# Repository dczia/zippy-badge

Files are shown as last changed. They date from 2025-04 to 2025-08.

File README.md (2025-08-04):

```
 ______                   ____            _            
|__  (_)_ __  _ __  _   _| __ )  __ _  __| | __ _  ___ 
  / /| | '_ \| '_ \| | | |  _ \ / _` |/ _` |/ _` |/ _ \
 / /_| | |_) | |_) | |_| | |_) | (_| | (_| | (_| |  __/
/____|_| .__/| .__/ \__, |____/ \__,_|\__,_|\__, |\___|
       |_|   |_|    |___/                   |___/      
```

DCZia Presents: The 2025 Zippy Badge

It blinks, it bloops*, it does stuff.

**Hardware**
* PiPico 2040 MCU
* Between 1 and 42 NeoPixel LEDs
* Microphone, accelerometer, and a SD card slot (not implemented, but go wild if you want)
* Powered by USB C or AA batteries.

\* Blooping not avaliable in all areas, not valid in NJ, void where prohibited, if you experience a rash or itching ask your doctor if blooping is right for you.

**User Manual**

As of Defcon, the UI is as follows - there is a four direction joystick on the right side of the badge. Clicking it in, will chnage modes, up and down will change brightness, and left and right do nothing for now. The first mode is the rainbow mode, mode 2 is accelerometer reactive and tilting the badge left, right, forward or back, will change the color. Mode 3 is a sound reactive party mode, and we tried to make an auto senseing volume / gain adjustment, but we will see if it works for parties, or if its just pegged. Power switch is on the bottom if you are using batteries, and the DFU programming buttion is well recessed (sorry) next to it. 

**Assembly / Disassembly**

The badge comes fully assembled. You can power it with a usb-c cable and a power supply of your choosing. You can also solder on the included AA battery pack. On the back of the board there are two pads, marked + and - Solder the red wire from the battery holder to the + and the black wire to the - 

Head to the HHV if you need help soldering. The case screws on with four screws. They are M2x4, self tapping or machine. You can download our shell design and print your own if you wish. Let us know if you make something cool!

**Programming / Updating**

The badge is powered by a Raspberry Pi 2040 MCU. You can find official docs for progamming here https://www.raspberrypi.com/products/rp2040/

The TL;DR is - copy our repo, plug the badge into your computer and you should see a drive appear (or not if you rolled your own linux distro that has no automounter, but you probably know what to do here already, if thats you) called "Circuitpython" Drag the files inside our repo's software directory to that drive (the .py files, and library folders). After the files are copied the badge should reboot with the new code. Sometimes the badge can reboot early and get in a weird state. You can delete everything on the drive and try again. If the badge is in a really weird state, you can hold down the bootloader button while the badge is unplugged, plug it in, and you should see a different named drive appear. Here you can drop our U2F firmwre blob which has circuitpython and our code in one file to update the badge. Hit us up on Discord / BSky if you have questions, or drop an issue here.

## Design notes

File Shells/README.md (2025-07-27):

# Zippy Shell

The DCZia Zippy Badge was designed with a translucent shell to both protect the electronics as well as to give that retro vibe.  Included here are the source files for the shell so you can make your own.

The SolidWorks files were made with the Maker's edition, which may give you problems if you actually have access to the real version.

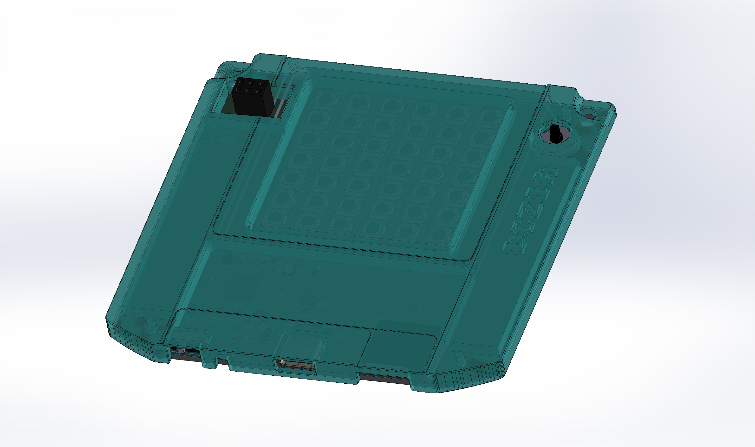
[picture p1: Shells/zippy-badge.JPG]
Badge


Additionally, a STEP file of the PCB board is provided, along with the SolidWorks assembly of the whole badge so you can see how your modeling changes affect the shell.

STEP is a bit better for doing changes with in CAD.  STL is what most slicers use, so you can use your slicer to make mods as well - but you can usually import STEP files as well.

Two different shells are provided:  

## Flat
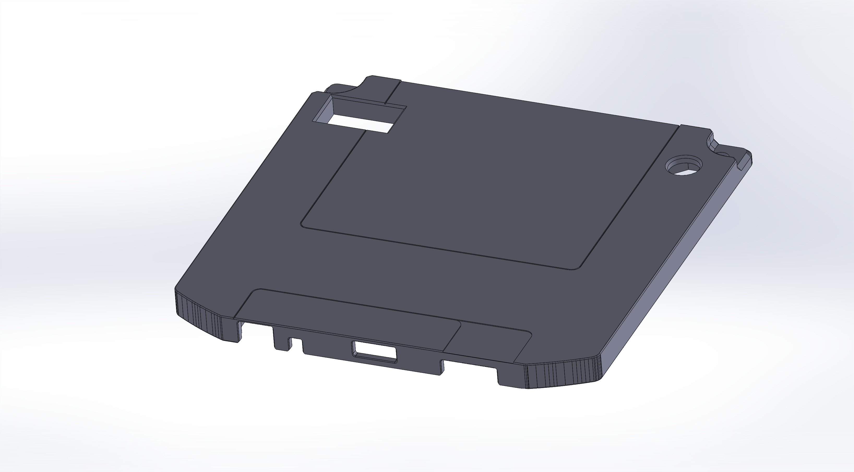
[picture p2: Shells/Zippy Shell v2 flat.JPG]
Flat
 

The 'flat' one is designed to work on a FDM printer.  Print it with the flat side down.  10% infill is good enough.

## Curved
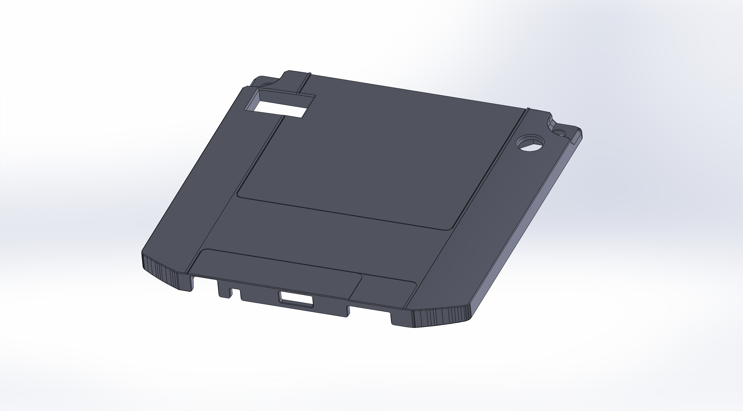
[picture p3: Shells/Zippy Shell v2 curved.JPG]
Curved


The 'curbed' one is like the original Zip disk with the curved outer edges.  This one works well for resin printing.

## Mounting

To mount the shell, there are 4 bolt holes provided, that work with M2 bolts, 4mm long.  Press firmly as you screw in - the plastic easily strips, but this method also works pretty well at this size, so... good luck.  The bolt hole locations are circled in red.

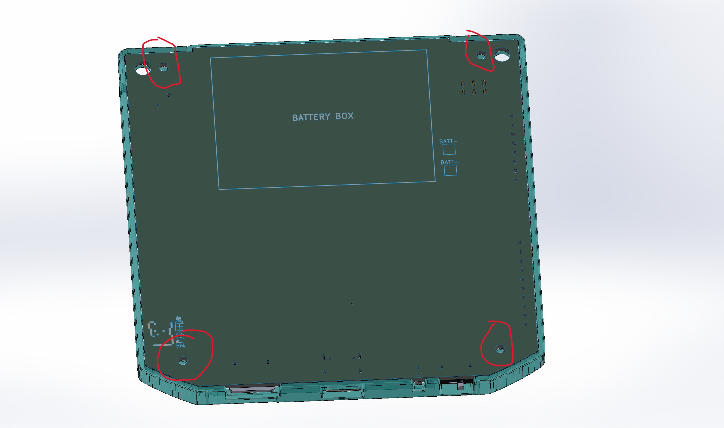
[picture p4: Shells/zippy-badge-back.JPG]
Bolts


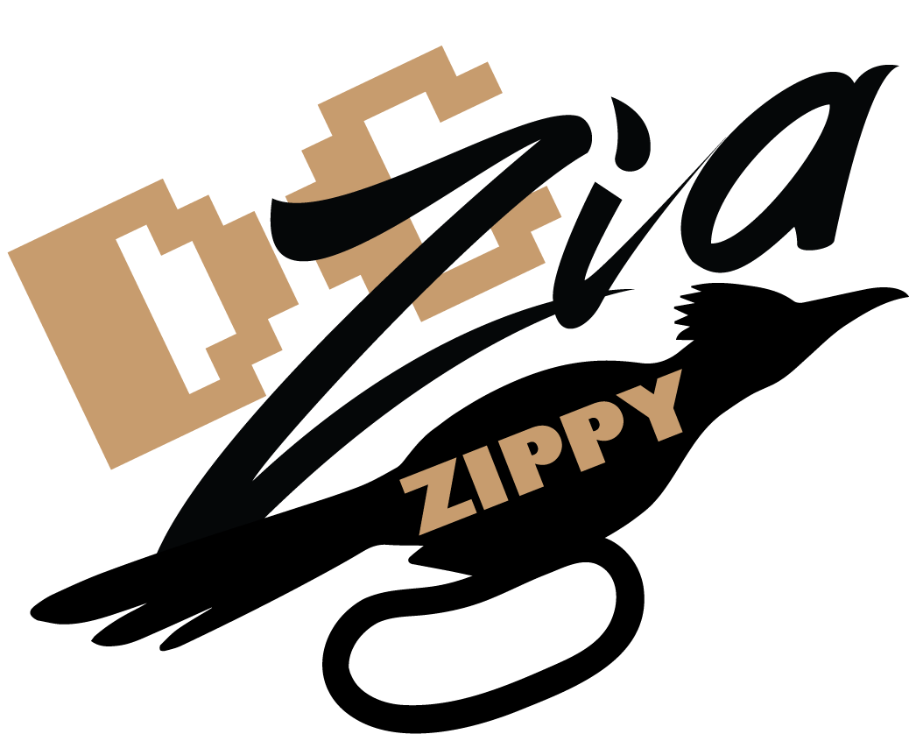
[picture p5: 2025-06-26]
Hardware/images/dczia zippy.png

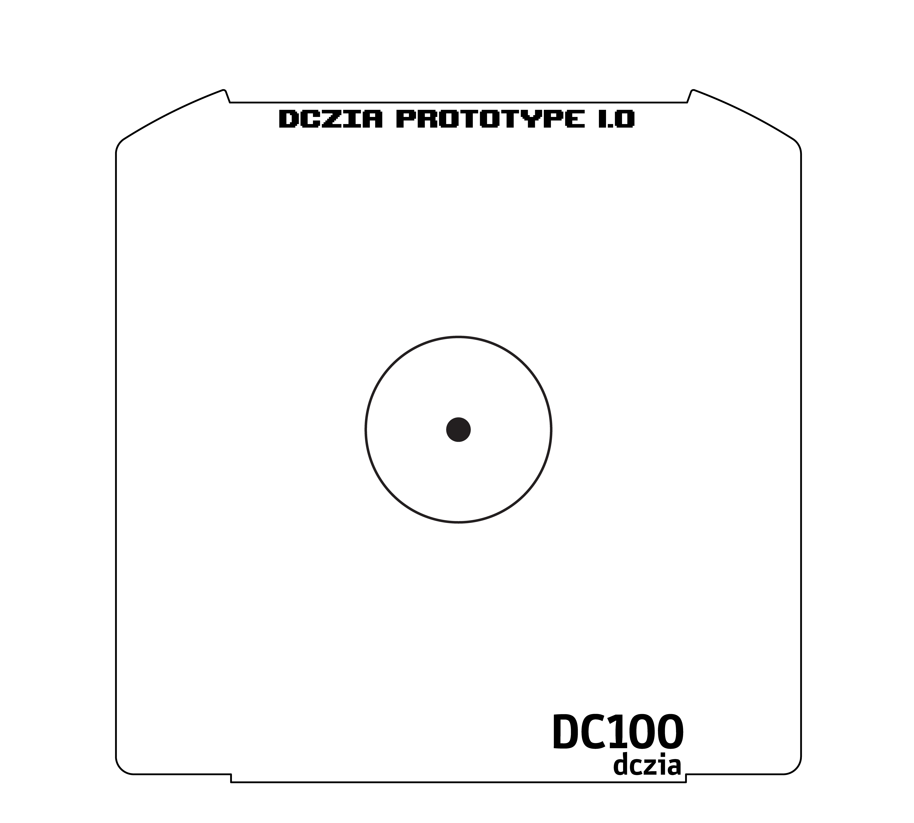
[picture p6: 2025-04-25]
Hardware/images/Proto Uno/ZipDisk100MBASM-02.png

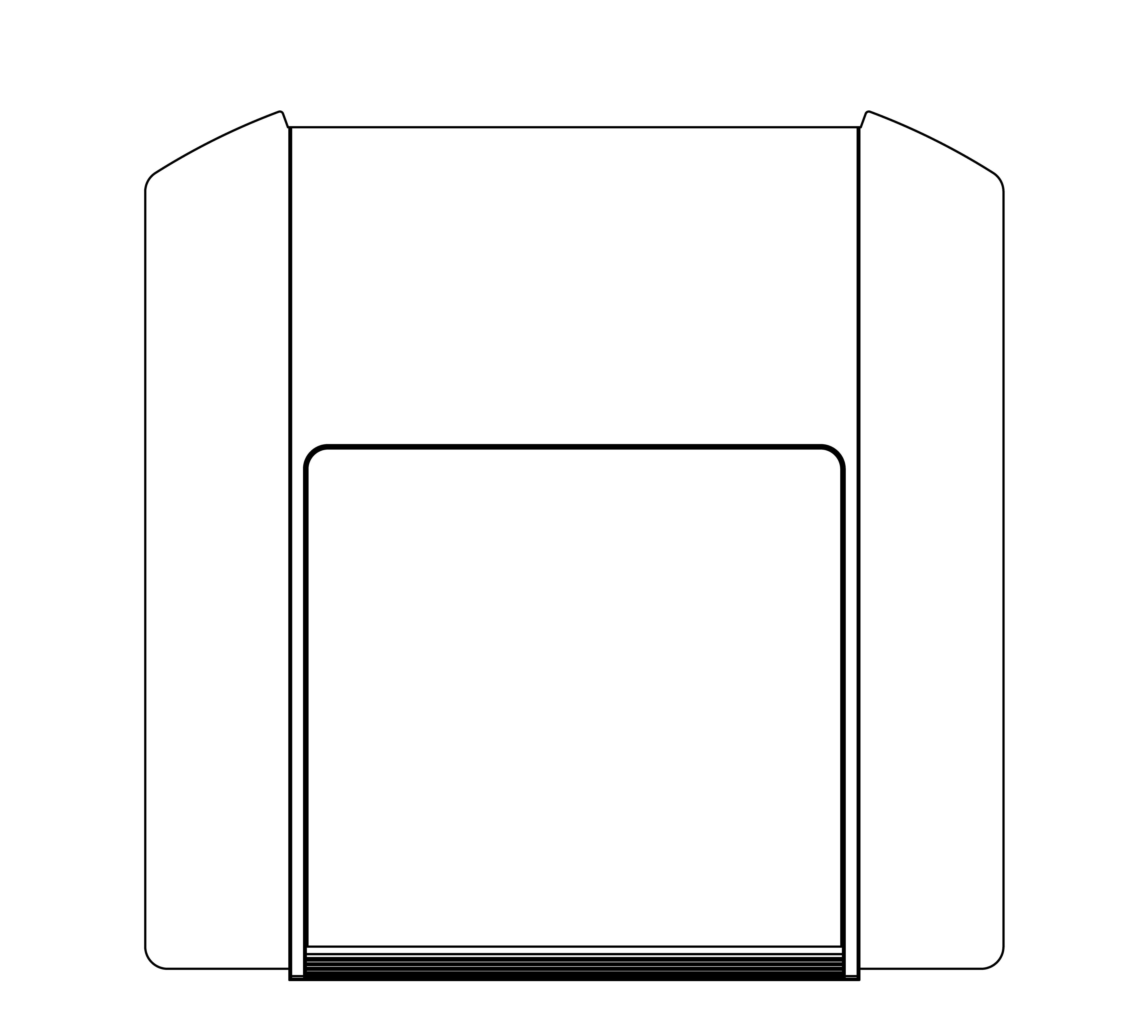
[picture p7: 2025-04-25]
Hardware/images/Proto Uno/ZipDisk100MBASM-01.png

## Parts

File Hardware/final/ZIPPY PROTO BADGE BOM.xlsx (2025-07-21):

Reference | Feeder | Value | Footprint | Part Number | Distributor | Distributor Part | Datasheet | Qty | Cost Each | Cost per Badge | Qty Needed | Qty Ordered | QOH | Notes
C1, C2, C3, C4, C5, C6, C7, C12, C15, C16, C17, C18, C19, C20, C21, C22 |  | 0.1uF | 0603 |  |  |  | ~ | 14 | 0.004 | 0.056 | 0 | 0 | 5000
C8,C9,C10,C14 |  | 1uF | 0603 |  |  |  | ~ | 4 | 0.004 | 0.016 | 0 | 4000
C11,C13 |  | 15pF | 0603 |  |  |  | ~ | 2 | 0.004 | 0.008 | 0 | 4000
D1, D45 |  | D_Schottky | Diode_SMD:D_SOD-523 |  |  |  | ~ | 2 | 0.11 | 0.22 | 100 |  | 0
D2,D3,D4,D5,D6,D7,D8,D9,D10,D11,D12,D13,D14,D15,D16,D17,D18,D19,D20,D21,D22,D23,D24,D25,D26,D27,D28,D29,D30,D31,D32,D33,D34,D35,D36,D37,D38,D39,D40,D41,D42,D43 |  | WS2812B | LED_SMD:LED_WS2812B_PLCC4_5.0x5.0mm_P3.2mm |  | Aliexpress | https://www.aliexpress.us/item/2251832628463811.html | https://cdn-shop.adafruit.com/datasheets/WS2812B.pdf | 42 | 0.07 | 2.94
D44 |  | TVS |  | SP0502BAHTG | Mouser | 576-SP0502BAHTG | https://www.littelfuse.com/assetdocs/tvs-diode-array-spasp050xba-lead-free-green-datasheet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 | 0 | 0.383 | 0 |  |  |  | Optional stuffing
J1 |  | Micro_SD_Card_SPI | lib_fp:MicroSD-Socket-Seeed-320090008 |  | Aliexpress |  | https://statics3.seeedstudio.com/images/opl/datasheet/320090008.pdf | 1 | 0.08 | 0.1 | 0 | 0
J2 |  | USB-C | Connector_USB:USB_C_Receptacle_HCTL_HC-TYPE-C-16P-01A |  | Aliexpress | https://www.aliexpress.us/item/3256805324706422.html | https://www.lcsc.com/datasheet/lcsc_datasheet_2211161000_HCTL-HC-TYPE-C-16P-01A_C2894897.pdf | 1 | 0.19 | 0.2 | 0 | 0
J3 |  | 1x8 Pin Header |  |  |  |  |  |  |  |  |  |  |  | DNS
J4 |  | 1x10 Pin Header |  |  |  |  |  |  |  |  |  |  |  | DNS
R1,R8 |  | 1k | 0603 |  |  |  | ~ | 2 | 0.001 | 0.002 | 0 | 0 | 5000
R2,R7 |  | 10k | 0603 |  |  |  | ~ | 2 | 0.001 | 0.002 | 0 | 0 | 5000
R3,R4 |  | 5.1k | 0603 |  |  |  | ~ | 2 | 0.001 | 0.002 |  | 5000
R5,R6 |  | 27R | 0603 |  |  |  | ~ | 2 | 0.001 | 0.002 |  | 5000
R9 |  | 10R | 0603 |  |  |  | ~ | 1 | 0.001 | 0.001 | 0 | 0 | 5000
SW1 |  | Boot Select | Button_Switch_SMD:SW_SPST_EVQP7C | EVQ-P7C01P | Mouser | 667-EVQP7C01P | ~ | 1 | 0.214 | 0.214 |  | 150
SW2 |  | SW_SPDT | lib_fp:SW_SPDT_CK-JS102011SAQN | JS102011SAQN | Mouser | 611-JS102011SAQN | https://ckswitches.com/media/1422/js.pdf | 1 | 0.463 | 0.463 |  | 150
SW3 |  | D-Pad | SKRHABE010 | SKRHABE010 | Mouser | 688-SKRHAAE010 | https://www.mouser.com/datasheet/2/15/SKRH-1370966.pdf | 1 | 2.02 | 2.02 | 0 | 0
TP1 |  | BATT+ | TestPoint:TestPoint_Pad_2.5x2.5mm | VIRTUAL |  |  | ~ | 1 |  | 0
TP2 |  | BATT- | TestPoint:TestPoint_Pad_2.5x2.5mm | VIRTUAL |  |  | ~ | 1 |  | 0
TP3 |  | SWCLK | TestPoint:TestPoint_Pad_2.5x2.5mm | VIRTUAL |  |  | ~ | 1 |  | 0
TP4 |  | SWD | TestPoint:TestPoint_Pad_2.5x2.5mm | VIRTUAL |  |  | ~ | 1 |  | 0
TP5, TP6 |  | Spare |  | VIRTUAL
U1 |  | NCP115ASN330T2G | Package_TO_SOT_SMD:SOT-23-5 | NCP115ASN330T2G | Mouser | 863-NCP115ASN330T2G | http://www.st.com/resource/en/datasheet/ld39015.pdf | 1 | 0.099 | 0.099 | 0 | 0 | 3000
U2 |  | RP2040 | Package_DFN_QFN:QFN-56-1EP_7x7mm_P0.4mm_EP3.2x3.2mm | SC0914(7) | Mouser | 358-SC09147 | https://datasheets.raspberrypi.com/rp2040/rp2040-datasheet.pdf | 1 | 0.8 | 0.8 | 0 | 0
U3 |  | W25Q16JV | lib_fp:W25Q16JVUXIQ_WIN | W25Q32RVXHJQ TR | Mouser | 454-W25Q32RVXHJQTR | https://www.winbond.com/hq/support/documentation/downloadV2022.jsp?__locale=en&level=1 | 1 | 0.481 | 0.481 |  | 150
U4 |  | GSDA213 | Kionix_LGA-12_2x2mm_P0.5mm_LayoutBorder2x4y | GSDA213 | Digikey | 4786-GSDA213TR-ND | https://goodarksemi.com/docs/datasheets/mems/GSDA213_SDS.pdf | 1 | 0.5868 | 0.5868 | 0 | 150
MK1 |  | ICS-43434 | InvenSense_ICS-43434-6_3.5x2.65mm | ICS-43434 | Aliexpress |  |  | 1 | 1.084 | 1.084 | 0 | 175
X1 |  | Badgelife_sao_connector_v169bis | lib_fp:Badgelife-Shitty-v1.69bis | VIRTUAL |  |  |  | 1 |  | 0
Y1 |  | Crystal | Crystal:Crystal_SMD_3225-4Pin_3.2x2.5mm | ABM8-272-T3 | Mouser | 815-ABM8-272-T3 | https://www.mouser.com/datasheet/2/3/ABM8_272_T3-3392615.pdf | 1 | 0.409 | 0.409 |  | 150
` |  | Battery boxes |  |  | Aliexpress | https://www.aliexpress.us/item/3256806115765872.html |  | 1 | 0.506 | 0.506 |  | 125
 |  | PCB |  |  |  |  |  | 1 | 2.175 | 2.175 |  | 200
 |  | Batteries |  |  | Amazon |  |  | 3 | 0.15 | 0.45 |  | 300
 |  |  |  |  |  |  |  | Total Parts |  | 12.8368

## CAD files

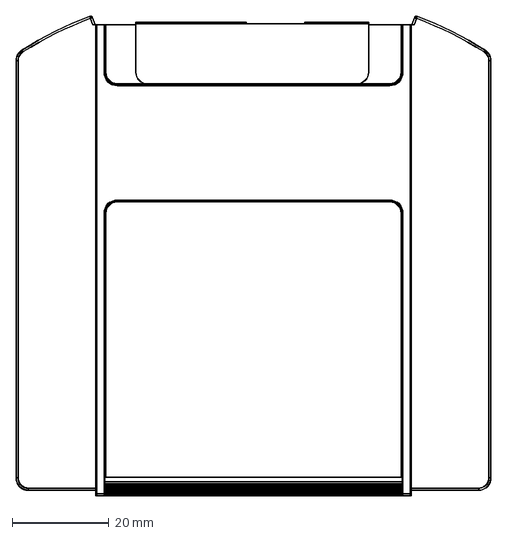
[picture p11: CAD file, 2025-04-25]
Hardware/images/Proto Uno/ZipDisk100MBASM.DXF
97.9 x 99.0 mm

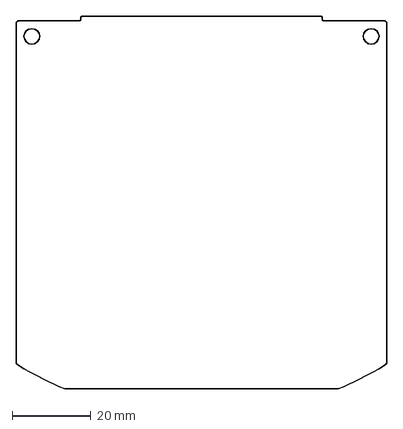
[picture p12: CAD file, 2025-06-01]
Hardware/images/Zippy Badge.dxf
94.4 x 94.9 mm

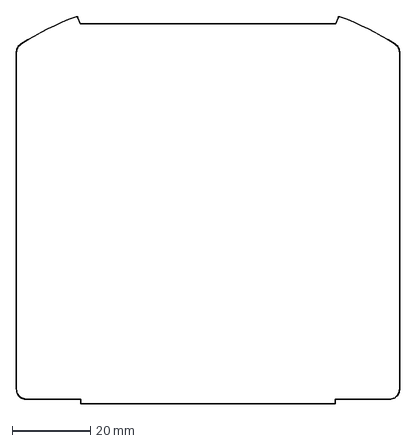
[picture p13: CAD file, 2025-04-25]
Hardware/images/Proto Uno/Zip Outline.dxf
97.9 x 99.0 mm

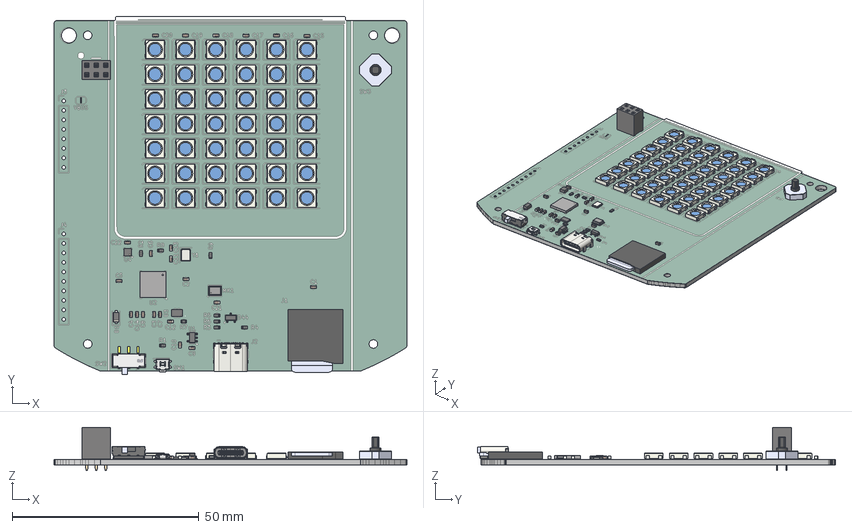
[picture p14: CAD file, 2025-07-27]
Shells/zippy-badge-PCB.step
94.4 x 95.9 x 11.6 mm
LED_WS2812B_PLCC4_5.0x5.0mm_P3.2mm x 42
C_0603_1608Metric x 22
USB_C_Receptacle_GCT_USB4105-xx-A_16P_TopMnt_Horizontal
SOT-23-3
SOT-23-5
R_0603_1608Metric x 9
SKRHABE010
JS102011SAQN
Crystal_SMD_Abracon_ABM8G-4Pin_3.2x2.5mm
Winbond_USON-8-1EP_3x2mm_P0.5mm_EP0.2x1.6mm
D_SOD-123F
MicroSD
PinSocket_2x03_P2.54mm_Vertical
QFN-56-1EP_7x7mm_P0.4mm_EP3.2x3.2mm
EVQP7-JA-01P
InvenSense_ICS-43434-6_3.5x2.65mm
LGA-12_2x2mm_P0.5mm
zippy-badge_silkscreen
zippy-badge_soldermask
zippy-badge_PCB

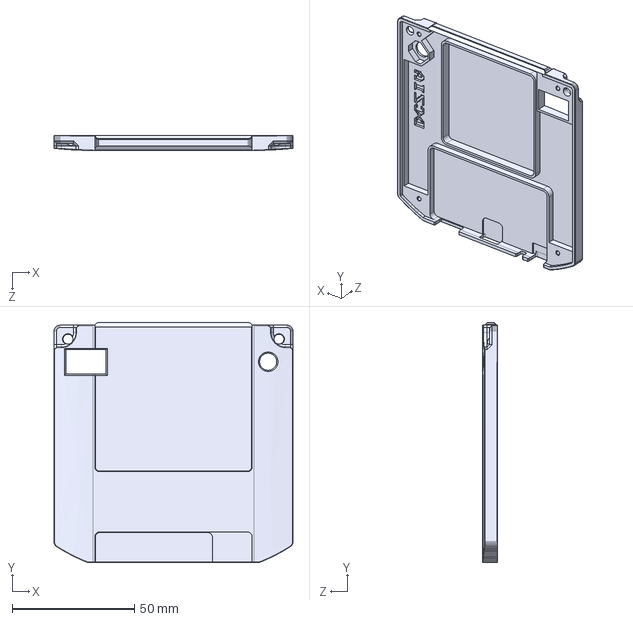
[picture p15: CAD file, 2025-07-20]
Shells/Zippy Shell v2 curved.STEP
97.9 x 98.4 x 6.30 mm

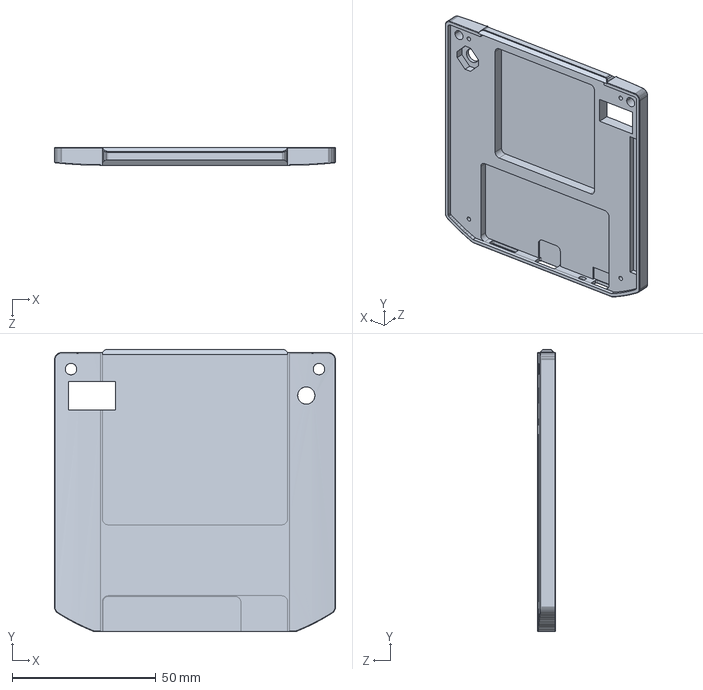
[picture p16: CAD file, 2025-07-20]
Shells/Zippy Shell v2.SLDPRT
97.9 x 98.4 x 6.30 mm

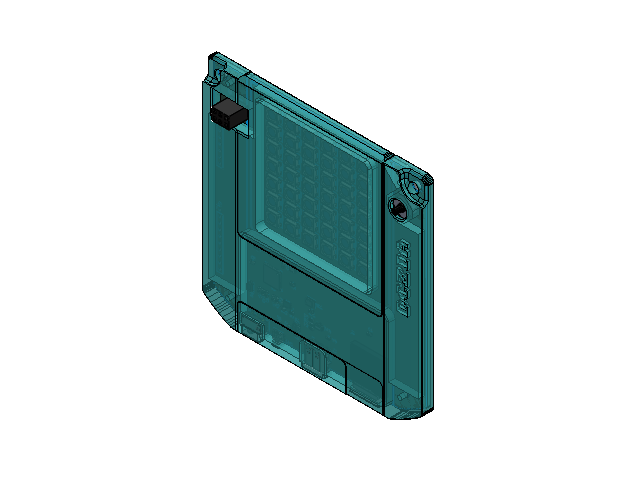
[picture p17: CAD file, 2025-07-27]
Shells/zippy-badge.SLDASM
Zippy Shell v2 curved
LED_WS2812B_PLCC4_5.0x5.0mm_P3.2mm x 42
C_0603_1608Metric x 22
USB_C_Receptacle_GCT_USB4105-xx-A_16P_TopMnt_Horizontal
SOT-23-3
SOT-23-5
R_0603_1608Metric x 9
SKRHABE010
JS102011SAQN
Crystal_SMD_Abracon_ABM8G-4Pin_3.2x2.5mm
Winbond_USON-8-1EP_3x2mm_P0.5mm_EP0.2x1.6mm
D_SOD-123F
MicroSD
PinSocket_2x03_P2.54mm_Vertical
QFN-56-1EP_7x7mm_P0.4mm_EP3.2x3.2mm
EVQP7-JA-01P
InvenSense_ICS-43434-6_3.5x2.65mm
LGA-12_2x2mm_P0.5mm
zippy-badge_silkscreen
zippy-badge_soldermask
zippy-badge_PCB

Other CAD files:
Hardware/3d/Winbond_USON-8-1EP_3x2mm_P0.5mm_EP0.2x1.6mm.SLDPRT
Hardware/3d/D_SOD-123F.SLDPRT
Hardware/3d/R_0603_1608Metric.SLDPRT
Hardware/3d/C_0603_1608Metric.SLDPRT
Hardware/3d/InvenSense_ICS-43434-6_3.5x2.65mm.SLDPRT
Shells/Zippy Shell v2 flat.STEP
Hardware/3d/SOT-23-3.SLDPRT
Shells/zippy-badge_silkscreen.SLDPRT
Hardware/3d/SOT-23-5.SLDPRT
Shells/zippy-badge_soldermask.SLDPRT
Hardware/3d/QFN-56-1EP_7x7mm_P0.4mm_EP3.2x3.2mm.SLDPRT
Hardware/3d/3AAA Battery Box - Flying Leads.SLDPRT
Hardware/3d/Crystal_SMD_Abracon_ABM8G-4Pin_3.2x2.5mm.SLDPRT
Hardware/3d/EVQP7-JA-01P.SLDPRT
Hardware/3d/EVQP7-JA-01P.STEP
Hardware/3d/JS102011SAQN.SLDPRT
Hardware/3d/JS102011SAQN.stp
Hardware/3d/LED_WS2812B_PLCC4_5.0x5.0mm_P3.2mm.SLDPRT
Hardware/3d/LGA-12_2x2mm_P0.5mm.SLDPRT
Hardware/3d/MicroSD.SLDPRT
Hardware/3d/MicroSD.STEP
Hardware/3d/PinSocket_2x03_P2.54mm_Vertical.SLDPRT
Hardware/3d/SKRHABE010.SLDPRT
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

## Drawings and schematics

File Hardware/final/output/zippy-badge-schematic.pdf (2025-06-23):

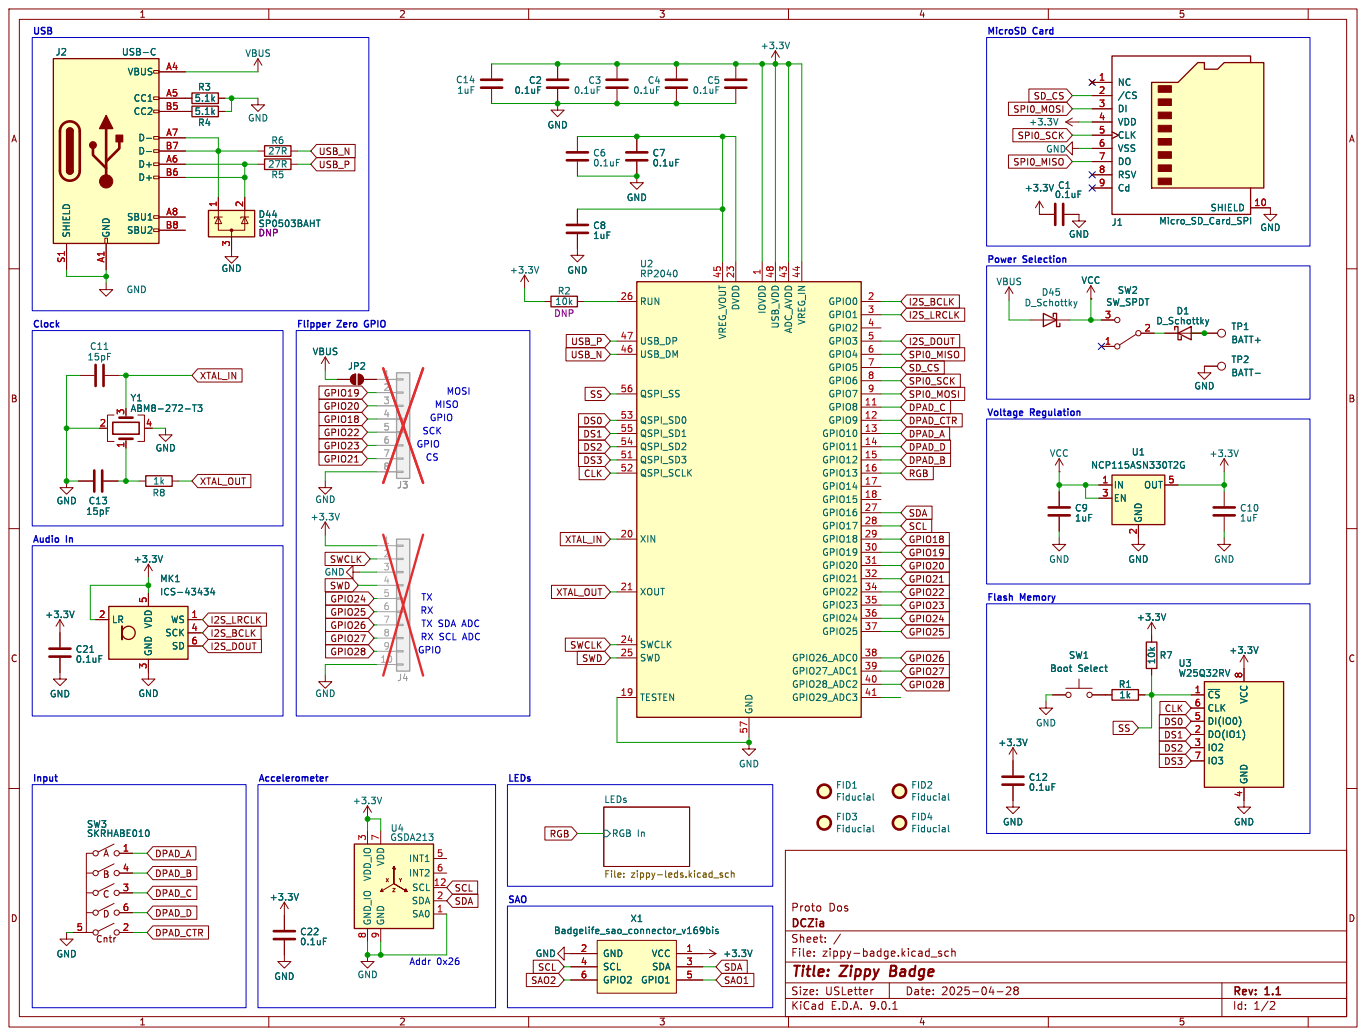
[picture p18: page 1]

3 WS 1 SCK 4 SD 6 GND

TX SDA ADC GPIO

Id: 1/2 Title: Zippy Badge

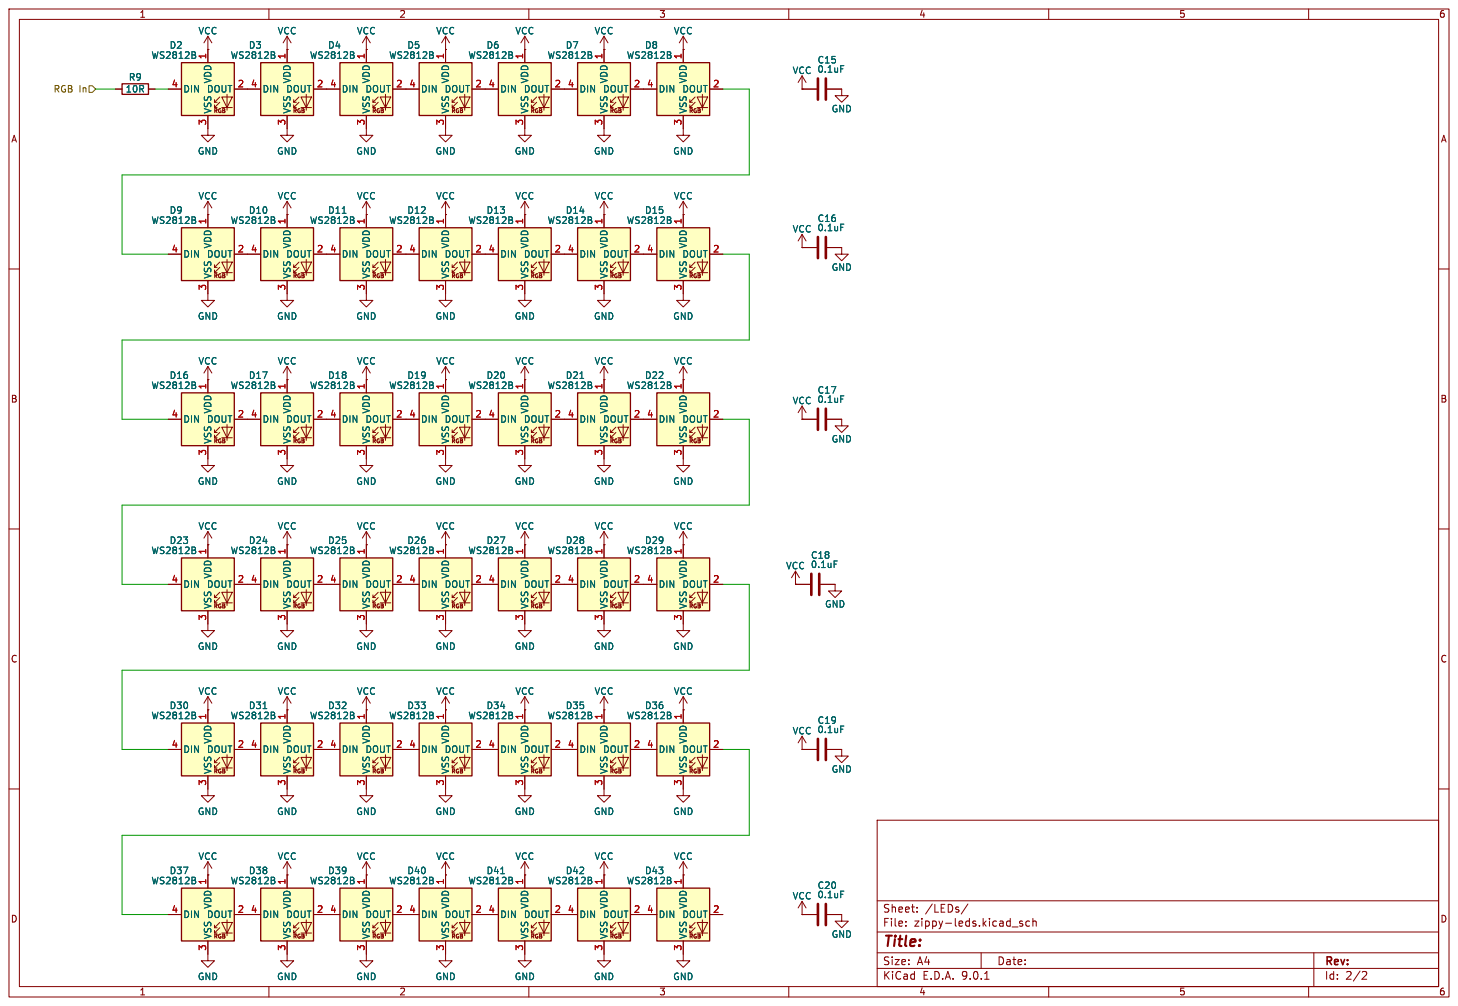
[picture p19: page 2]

3 DOUT 2 VCC GND GND

3 DOUT 2 D35 WS2812B GND GND GND

3 DOUT 2 GND GND GND

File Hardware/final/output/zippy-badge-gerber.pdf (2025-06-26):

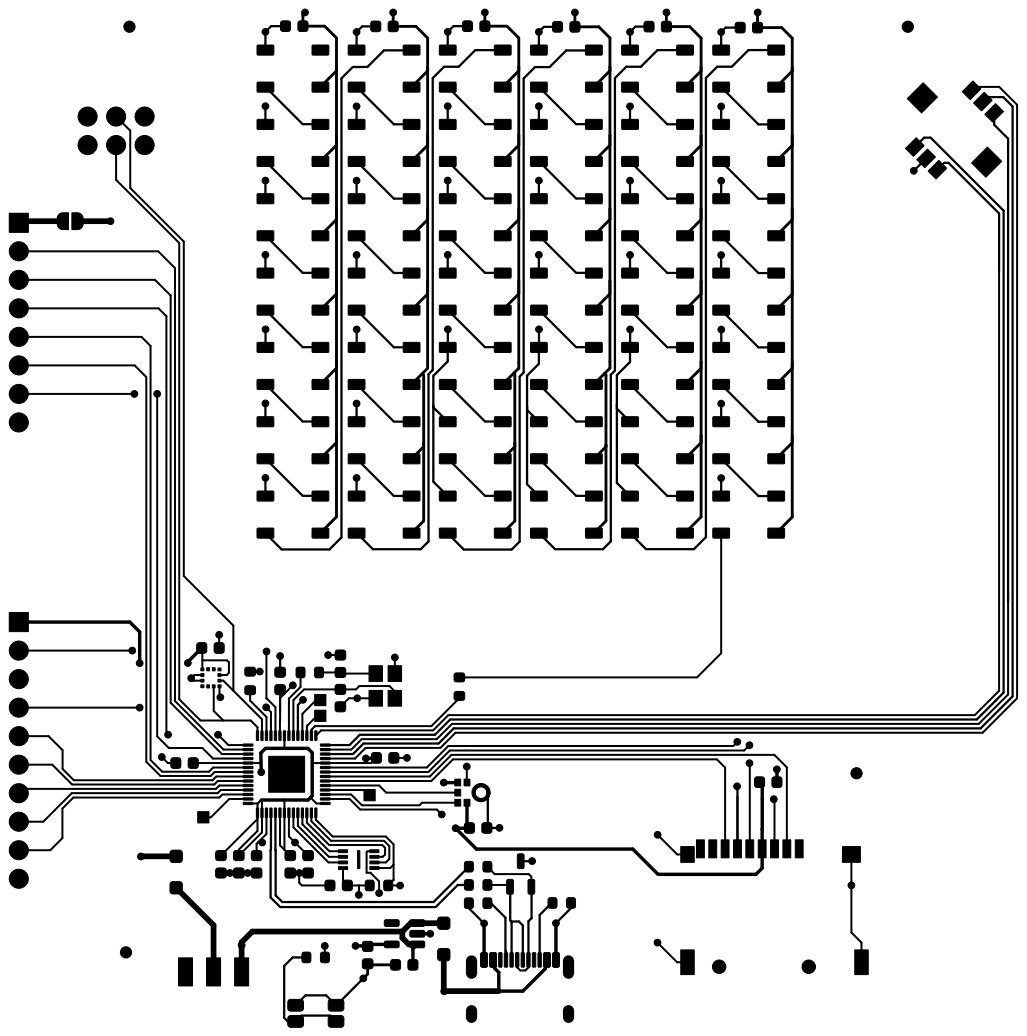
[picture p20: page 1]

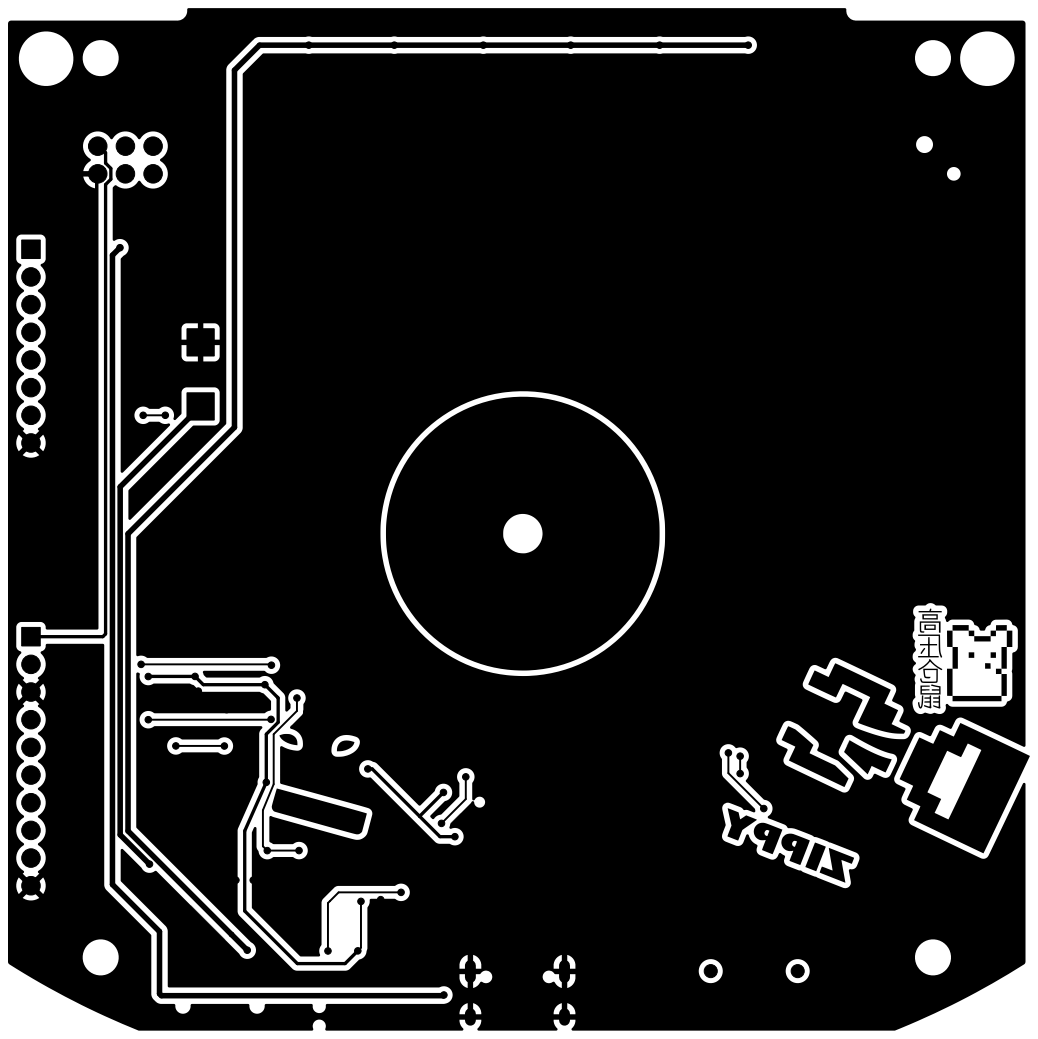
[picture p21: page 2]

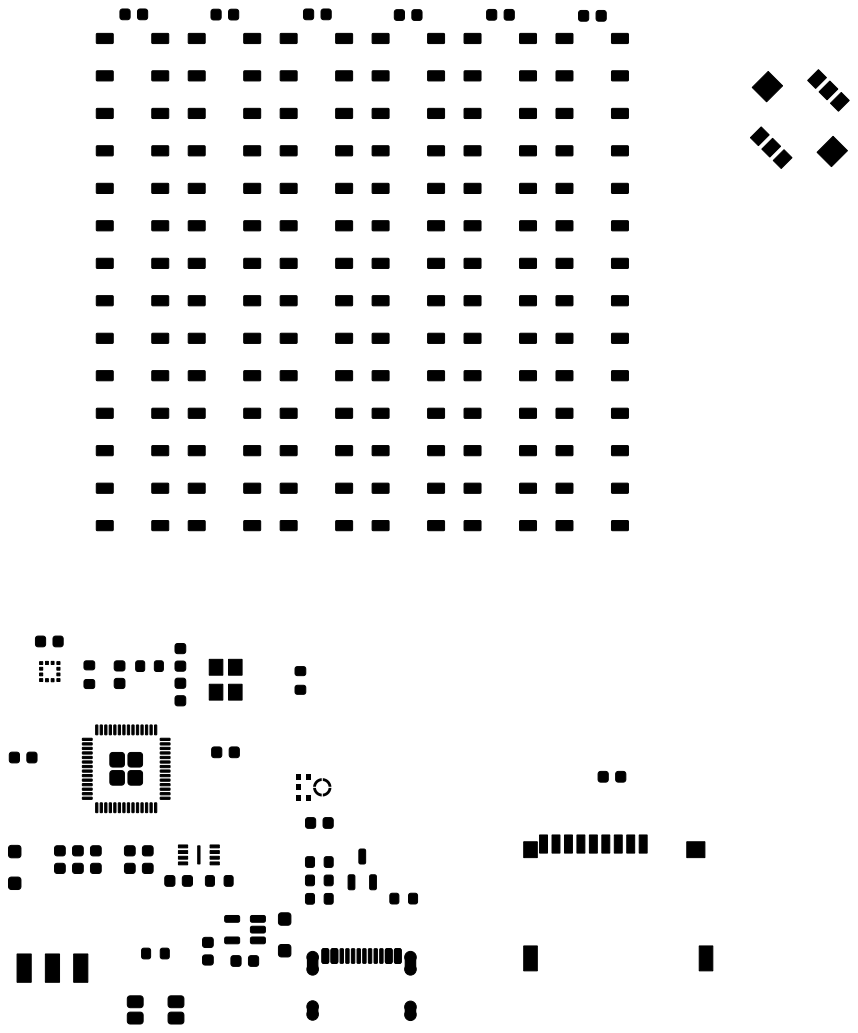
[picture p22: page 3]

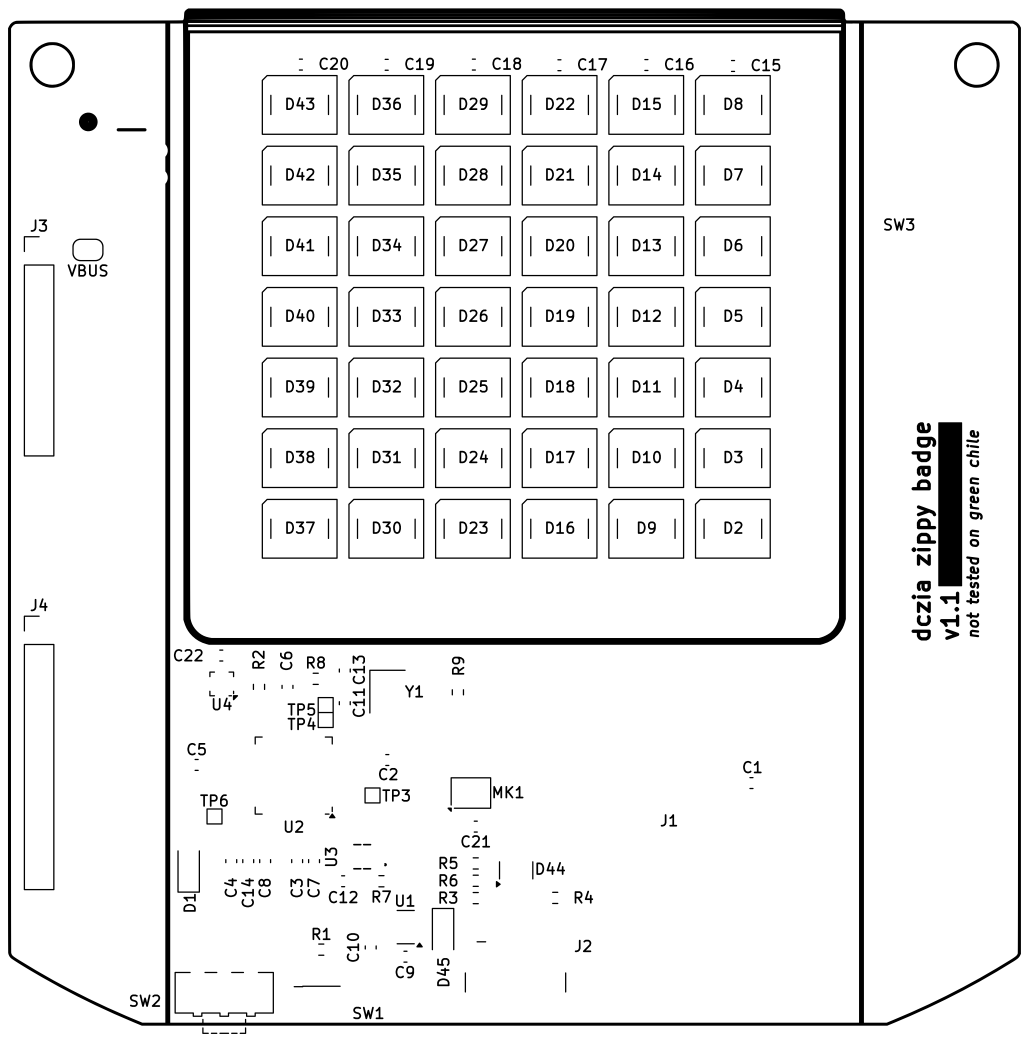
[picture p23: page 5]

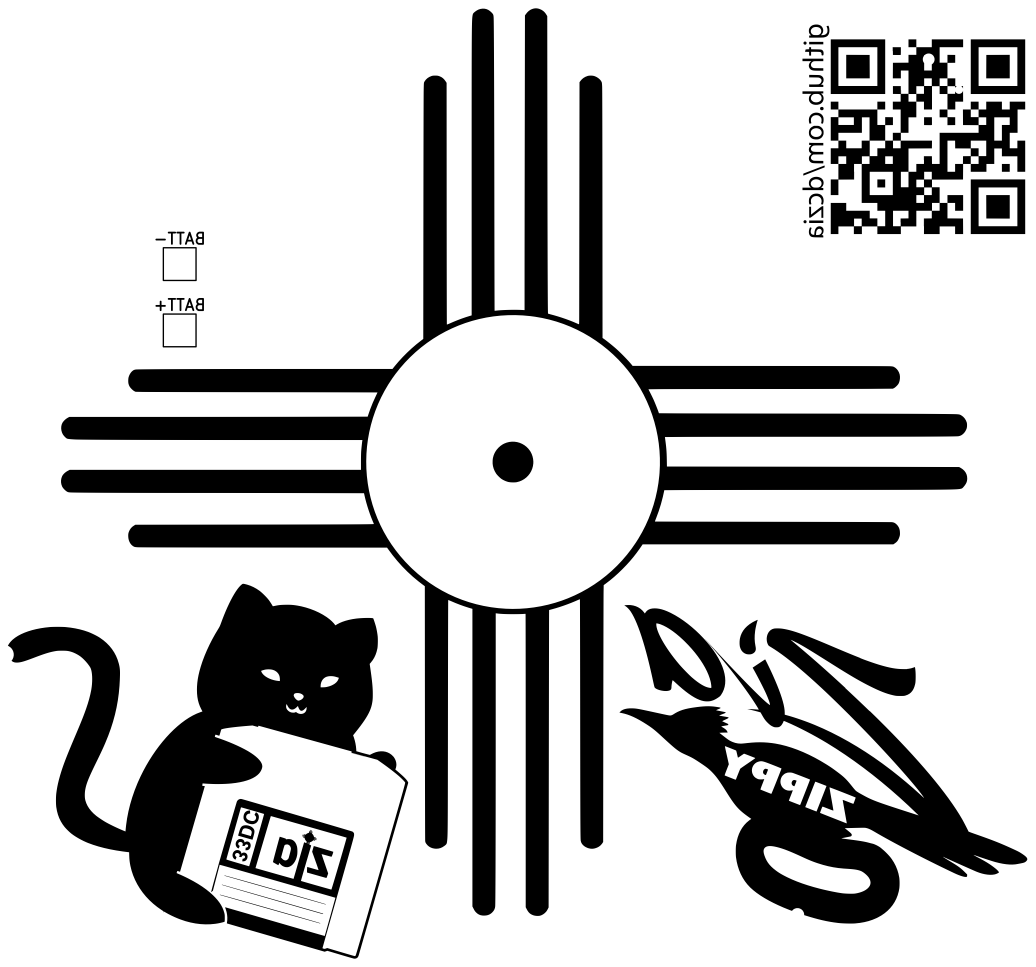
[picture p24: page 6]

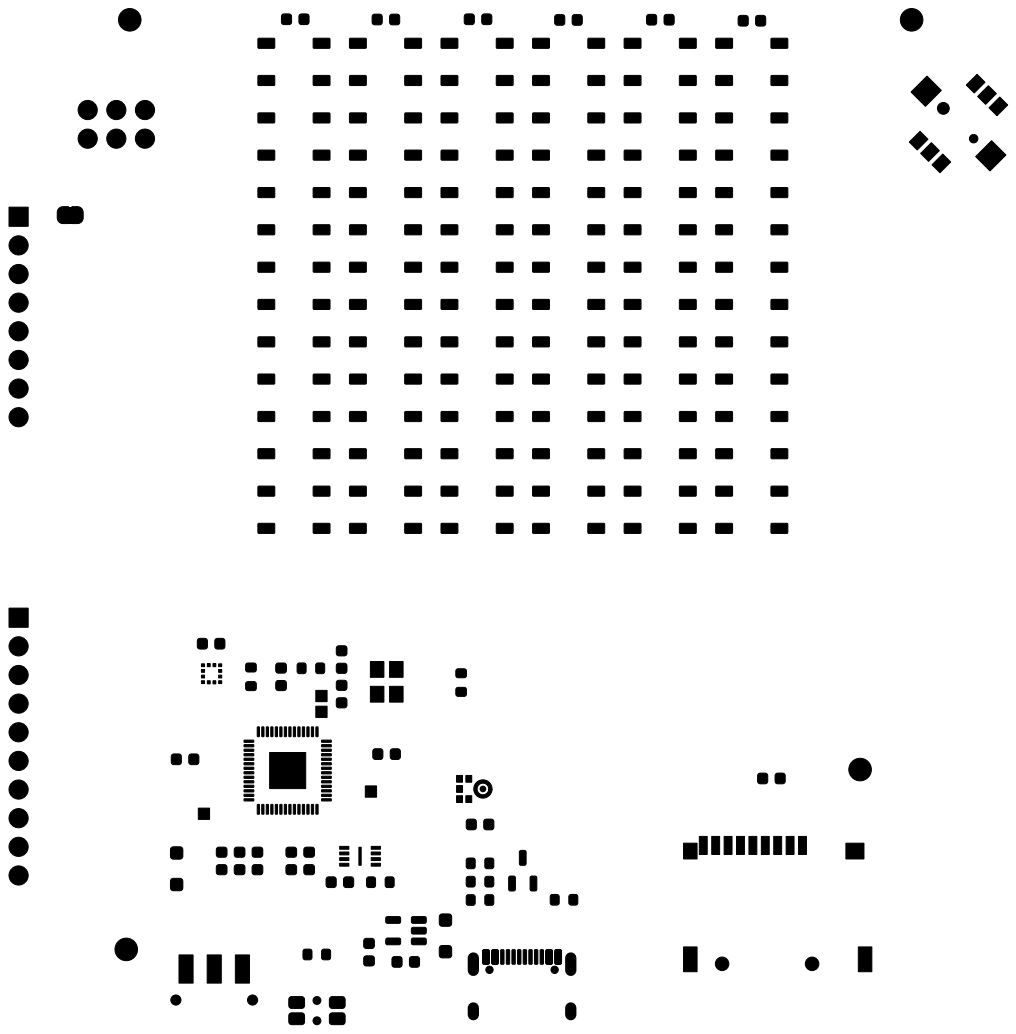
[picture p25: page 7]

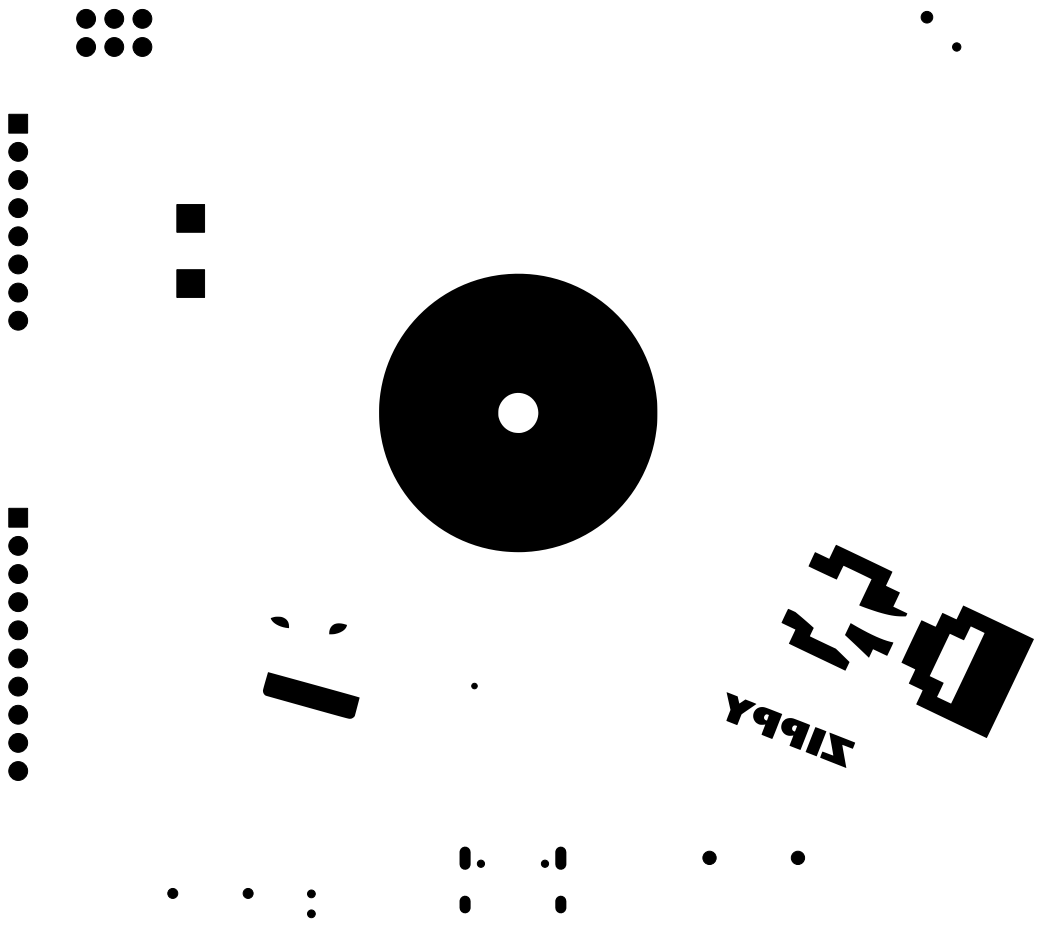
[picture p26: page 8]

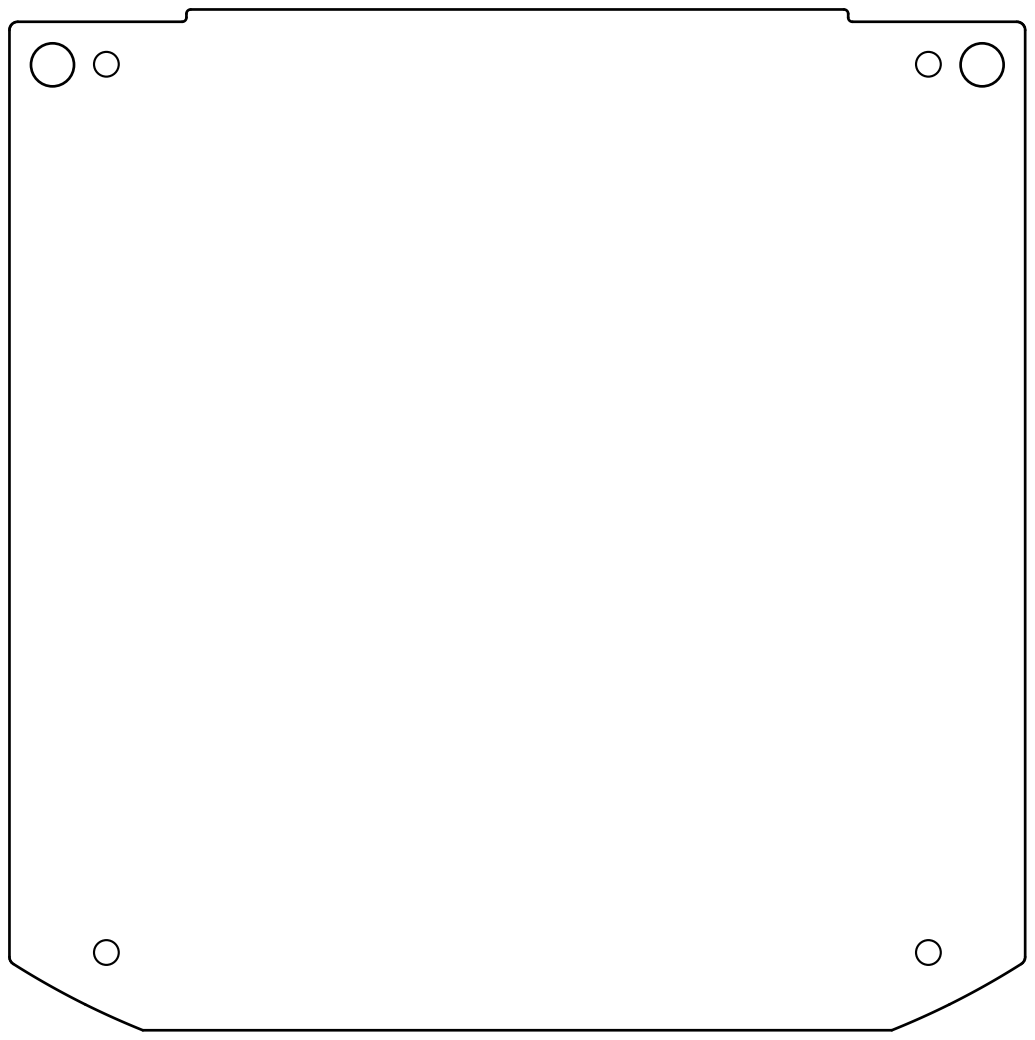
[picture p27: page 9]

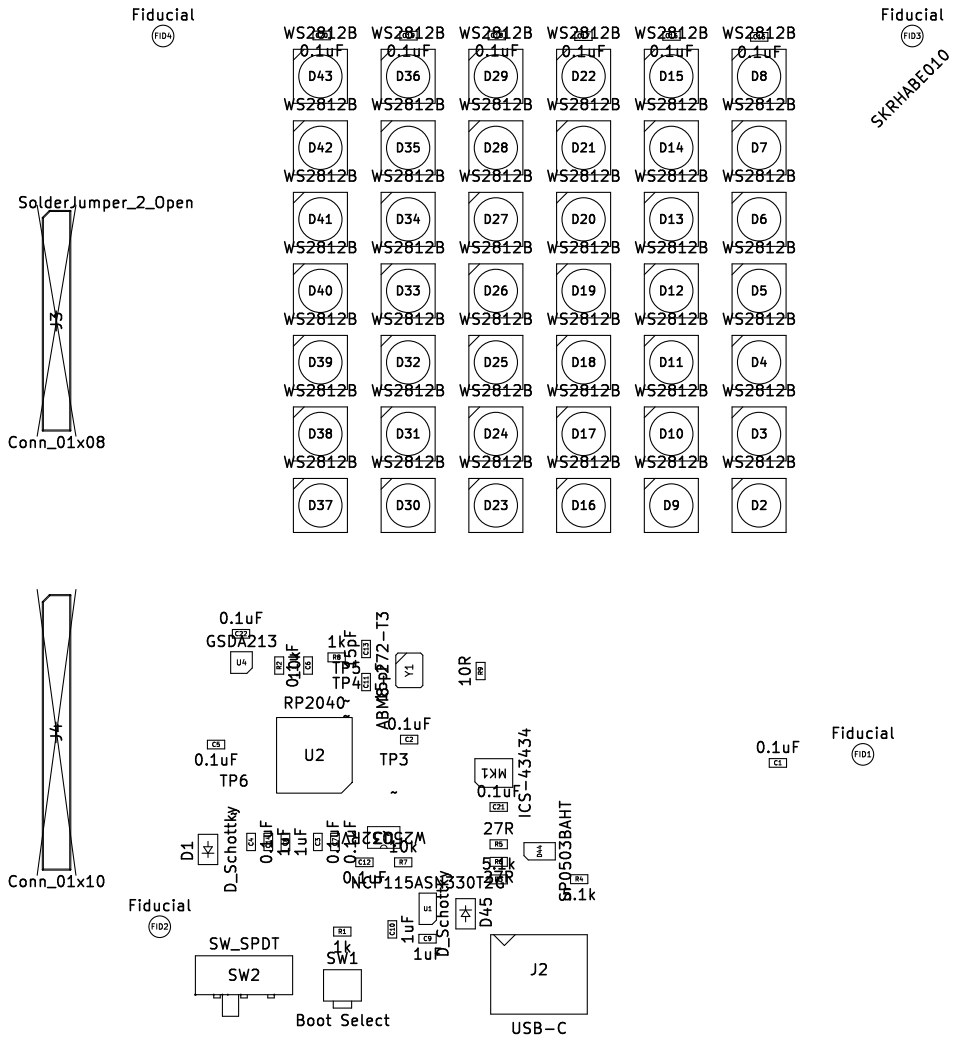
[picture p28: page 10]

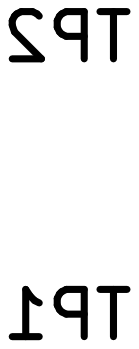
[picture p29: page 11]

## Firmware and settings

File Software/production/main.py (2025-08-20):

from state import StateMachine
from state_startup import StartupState
from state_party import PartyState
from state_rave import RaveState
from state_accel import AccelState
from state_scroll import ScrollState
from state_heckrave import HeckRaveState
from state_flashrave import FlashRaveState

core_machine = StateMachine()
core_machine.add_state(StartupState())
core_machine.add_state(PartyState())
core_machine.add_state(AccelState())
core_machine.add_state(RaveState())
core_machine.add_state(ScrollState())
core_machine.add_state(HeckRaveState())
core_machine.add_state(FlashRaveState())

core_machine.go_to_state("startup")

while True:
    core_machine.update()

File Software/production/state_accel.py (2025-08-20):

from setup import pixels, num_pixels
from setup import keys
from setup import sensor
from state import State
from rainbowio import colorwheel
import global_tools

# from menu import menu_select, show_menu, show_select


class AccelState(State):

    @property
    def name(self):
        return "accel"

    def __init__(self):
        self.hue = 0
        self.target_hue = 0
        self.pattern_index = 0
        self.trail_positions = [0] * 8  # For pattern 2
        self.wave_offset = 0  # For pattern 3

    def enter(self, machine):
        self.exit_flag = False
        State.enter(self, machine)

    def exit(self, machine):
        pixels.fill((0, 0, 0))
        pixels.show()
        State.exit(self, machine)

    def update(self, machine):
        pattern_count = 3
        # Check for button press
        event = keys.events.get()
        if event:
            if event.pressed:
                if event.key_number == 1:
                    self.exit_flag = True

                # Next pattern
                elif event.key_number == 2:
                    self.pattern_index = (
                        self.pattern_index + 1) % pattern_count
                # Previous pattern
                elif event.key_number == 3:
                    self.pattern_index = (
                        self.pattern_index - 1) % pattern_count

                # Brightness controls
                elif event.key_number == 0:
                    if global_tools.current_brightness <= 0.45:
                        global_tools.current_brightness += 0.05
                    else:
                        global_tools.current_brightness = 0.5
                    pixels.brightness = global_tools.current_brightness

                elif event.key_number == 4:
                    if global_tools.current_brightness >= 0.05:
                        global_tools.current_brightness -= 0.05
                    else:
                        global_tools.current_brightness = 0.0
                    pixels.brightness = global_tools.current_brightness

        if self.exit_flag is True:
            machine.go_to_state("party")

        else:
            # Get accelerometer data
            acc_x, acc_y, acc_z = sensor.acceleration

            if self.pattern_index == 0:
                # Pattern 0: Original color direction pattern
                if abs(acc_z) > 3:  # Significant vertical movement
                    if acc_z > 0:  # Moving up
                        self.target_hue = 42  # Orange
                    else:  # Moving down
                        self.target_hue = 128  # Cyan
                elif abs(acc_x) > abs(acc_y):
                    if acc_x > 0:  # Tilted right
                        self.target_hue = 0  # Red
                    else:  # Tilted left
                        self.target_hue = 85  # Green
                else:
                    if acc_y > 0:  # Tilted forward
                        self.target_hue = 170  # Blue
                    else:  # Tilted back
                        self.target_hue = 255  # Purple

            elif self.pattern_index == 1:
                # Pattern 1: Intensity-based pattern
                # Use total acceleration to determine color intensity
                total_acc = (acc_x ** 2 + acc_y ** 2 + acc_z ** 2) ** 0.5
                # More movement = more color change
                self.target_hue = int((total_acc * 20) % 256)

            elif self.pattern_index == 2:
                # Pattern 2: Tilt Level Meter
                # Move colors based on tilt angle
                # Convert tilt to pixel position
                tilt_x = int((acc_x + 10) * (num_pixels/20))
                # Constrain to valid pixel range
                tilt_x = max(0, min(num_pixels-1, tilt_x))

                # Update trail positions
                self.trail_positions = [tilt_x] + self.trail_positions[:-1]

                # Clear pixels
                pixels.fill((0, 0, 0))

                # Draw trail with fading colors
                for i, pos in enumerate(self.trail_positions):
                    if 0 <= pos < num_pixels:
                        color = colorwheel((self.hue + i * 30) % 256)
                        pixels[pos] = color

                # Skip the normal color fill
                pixels.show()
                self.hue = (self.hue + 1) % 256
                return

            # Smooth fade towards target hue
            if self.hue != self.target_hue:
                if self.hue < self.target_hue:
                    if self.target_hue - self.hue > 128:
                        self.hue = (self.hue - 1) % 256
                    else:
                        self.hue = (self.hue + 1) % 256
                else:
                    if self.hue - self.target_hue > 128:
                        self.hue = (self.hue + 1) % 256
                    else:
                        self.hue = (self.hue - 1) % 256

            # Get the current color
            color = colorwheel(self.hue)

            # Fill the entire LED grid with the color
            pixels.fill(color)
            pixels.show()

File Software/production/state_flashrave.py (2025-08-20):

import time

from ulab import numpy as np
from ulab.utils import spectrogram

from setup import pixels
from setup import mic
from state import State
from setup import keys
import global_tools


class FlashRaveState(State):

    @property
    def name(self):
        return "flashrave"

    def __init__(self):
        self.previous_intensity = 0
        self.volume = 0.5
        self.max = 1

    def enter(self, machine):
        pixels.fill((0, 0, 0))
        self.max_intensity = 0
        self.volume = 1
        self.previous_input = "none"
        self.running_max = 0
        self.running_min = 0
        self.exit_flag = False
        self.columnColor = 0
        State.enter(self, machine)

    def exit(self, machine):
        pixels.fill((0, 0, 0))
        pixels.show()
        State.exit(self, machine)

    def update(self, machine):
        columnColor = [
            (255, 0, 0),
            (255, 0, 115),
            (0, 0, 255),
            (0, 255, 0),
            (255, 255, 0),
            (155, 155, 155)
        ]

        # Poll for key press and cycle to next mode
        event = keys.events.get()
        if event:
            if event.pressed:
                if event.key_number == 1:
                    self.exit_flag = True

                # Brightness controls
                elif event.key_number == 0:
                    if global_tools.current_brightness <= 0.45:
                        global_tools.current_brightness += 0.05
                    else:
                        global_tools.current_brightness = 0.5
                    pixels.brightness = global_tools.current_brightness

                elif event.key_number == 2:
                    # right
                    if self.columnColor < len(columnColor) - 1:
                        self.columnColor += 1
                    else:
                        self.columnColor = 0
                elif event.key_number == 3:
                    # left
                    if self.columnColor == 0:
                        self.columnColor = len(columnColor) - 1
                    else:
                        self.columnColor -= 1

                elif event.key_number == 4:
                    if global_tools.current_brightness >= 0.05:
                        global_tools.current_brightness -= 0.05
                    else:
                        global_tools.current_brightness = 0.0
                    pixels.brightness = global_tools.current_brightness

        if self.exit_flag is True:
            machine.go_to_state("accel")

        else:
            try:
                # Get mic sample
                samples = np.array(
                    mic.read(block=True), dtype=np.int16
                )  # Record batch of 16-bit samples
                # Fix jankery due to mic by dropping even indexed samples
                samples = samples[1::2]

                # FFT
                spectrum = spectrogram(samples)

                # Log and binning to make cleaner, binning could be improved
                data = np.log(spectrum + 1e-7)
                data = np.interp(
                    np.arange(0, len(data), len(data) / 64, dtype=np.float),
                    np.arange(0, len(data), 1, dtype=np.uint16),
                    data,
                )

                bins = [data[12], data[12], data[12],
                        data[12], data[12], data[12]]

                # Calculate running max for auto_scaling
                self.running_max = (self.running_max * 24 + max(bins)) / 25
                self.running_min = (self.running_min * 24 + min(bins)) / 25

                # Fill pixels based on values
                pixels.fill((0, 0, 0))
                for index, item in enumerate(bins):
                    step = (self.running_max - self.running_min) / 7
                    if item > step + self.running_min:
                        pixels[(index) * 7] = columnColor[self.columnColor]
                    if item > step * 2 + self.running_min:
                        pixels[(index) * 7 + 1] = columnColor[self.columnColor]
                    if item > step * 3 + self.running_min:
                        pixels[(index) * 7 + 2] = columnColor[self.columnColor]
                    if item > step * 4 + self.running_min:
                        pixels[(index) * 7 + 3] = columnColor[self.columnColor]
                    if item > step * 5 + self.running_min:
                        pixels[(index) * 7 + 4] = columnColor[self.columnColor]
                    if item > step * 6 + self.running_min:
                        pixels[(index) * 7 + 5] = columnColor[self.columnColor]
                    if item > step * 7 + self.running_min:
                        pixels[(index) * 7 + 6] = columnColor[self.columnColor]
                pixels.show()
            except:
                pass
            time.sleep(0.05)

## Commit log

2025-04-25 Adding zippy badge prototype
    [3AAA Battery Box - Flying Leads.SLDPRT, EVQP7-JA-01P.STEP, JS102011SAQN.SLDPRT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]
2025-04-29 Updating proto final
    [zippy-badge-B_Cu.gbr, zippy-badge-B_Mask.gbr, zippy-badge-B_Paste.gbr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]
2025-04-29 Moved first prototype to proto uno, duplicated to proto dos for second rev
    [ZIPPY PROTO BADGE BOM.xlsx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]
2025-04-29 Updated proto dos with accelerometer, microphone, and fixed the USB-C CC power detection
    [zippy-badge.kicad_sch]
2025-05-03 Moving hardware files into a hardware directory
    [3AAA Battery Box - Flying Leads.SLDPRT, EVQP7-JA-01P.STEP, JS102011SAQN.SLDPRT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]
2025-05-03 Updated schematic to add Flipper Zero GPIO pinout Modified pin out of RP2040 to make for better routing Update of PCB to add new parts and test layout
    [zippy-badge.kicad_pcb, zippy-badge.kicad_sch]
2025-05-09 Moved proto images to proto directory Updated outlines to reflect board size, which is slightly smaller than the shell size Flipped board view to reflect lanyard mounting holes
    [Zip Outline.dxf, ZipDisk100MBASM.DXF, Zippy Badge.dxf]
2025-05-25 Added framework for sound reactive rave mode. Note, the flashing after the scroll is currently random and can be a little intense.
2025-06-01 Updating artwork outlines to remove complexity at the bottom Adding 3D files for parts Adding STEP file for board Adding SolidWorks assembly for badge with shell
    [C_0603_1608Metric.SLDPRT, Crystal_SMD_Abracon_ABM8G-4Pin_3.2x2.5mm.SLDPRT, D_SOD-123F.SLDPRT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]
2025-06-01 Adding chamfers to the shell because chamfers separate us from the animals Adding a STEP file of the same
    [Zippy Shell.SLDPRT, Zippy Shell.STEP]
2025-06-23 Adding artwork to the back Added blocking diode for VBUS Added outputs
    [zippy-badge-B_Cu.gbr, zippy-badge-B_Fab.gbr, zippy-badge-B_Mask.gbr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]
2025-06-23 Adding updated artwork Adding generated footprints
2025-06-26 Final updates before board order
    [zippy-badge-B_Cu.gbr, zippy-badge-B_Fab.gbr, zippy-badge-B_Mask.gbr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]
2025-06-26 Renamed proto_dos to final
    [ZIPPY PROTO BADGE BOM.xlsx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]
2025-07-07 Updated the BOM Added part placement files
    [ZIPPY PROTO BADGE BOM.xlsx]
2025-07-18 fixing sd card mounting
2025-07-20 Modified the shell, have a flat one for FDM printers and a curved one for SLA
    [Zippy Shell v2 curved.SLDPRT, Zippy Shell v2 curved.STEP, Zippy Shell v2 curved.STL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]
2025-07-21 Update BOM
    [ZIPPY PROTO BADGE BOM.xlsx]
2025-07-23 Flipping DCZIA text the right way
    [state_startup.py]
2025-07-27 Moved the shells to a better directory and added a readme
    [Zippy Shell v2 curved.SLDPRT, Zippy Shell v2 curved.STEP, Zippy Shell v2 curved.STL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]
2025-07-30 Made the accelerometer better or worse?
